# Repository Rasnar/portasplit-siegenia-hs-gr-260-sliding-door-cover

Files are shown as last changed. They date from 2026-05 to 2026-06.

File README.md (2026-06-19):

# Midea Portasplit Cover for Siegenia HS GR 260 Sliding Door

A parametric OpenSCAD adapter designed to fit the Midea Portasplit hose into a Siegenia HS GR 260 sliding door rail. This repository includes a repeatable middle piece, optional hose cutout, and top/bottom end caps for a clean, stackable installation.

## Supported hardware

- Siegenia HS GR 260 sliding door rail
- Midea Portasplit hose

> This model is tuned for these components. If you use a different rail profile or hose, verify the fit before printing.

## Contents

- `default-adapter.scad` — repeatable middle piece with optional hose slot
- `end-cap.scad` — top and bottom finishing caps for the assembly
- `default-adapter.3mf`, `portasplit-siegenia-adapter.3mf` — 3MF project files
- `default-adapter-10cm.stl`, `default-adapter-15cm.stl`, `default-adapter-20cm.stl` — preview STL exports
- `end-cap-top.stl`, `end-cap-bottom.stl` — cap preview models
- `LICENSE` — GNU GPLv3 license

## What this project does

This design creates a sliding-door-friendly cover for the Midea Portasplit hose inside the Siegenia HS GR 260 door rail. It uses:

- door-side tenons to engage the sliding door channel
- wall-side mortises and a center channel for fixed pin clearance
- dovetail-style tongues and grooves for vertical stacking
- an optional hose cutout that lets the hose pass through the part without detaching the assembly

## Recommended print setup

- Material: PETG is recommended for durability and fit
- Orientation: print vertically with the long face in Z
- Supports: minimal, only if your slicer requires them for small overhangs
- Layer height: 0.2mm or finer for best fit detail
- Tolerance: default `tolerance = 0.15`; adjust by ±0.05mm if the assembly feels too tight or loose

## Quick start

1. Open `default-adapter.scad` in OpenSCAD.
2. Set `hose_hole = true` to enable the hose slot, or `false` for a solid adapter piece.
3. Customize dimensions if needed, but keep the rail-specific interface values unless you are changing the rail geometry.
4. Render and export the model as STL or 3MF.
5. Use `end-cap.scad` with `part = "bottom"` for the bottom cap and `part = "top"` for the top cap.

## Usage examples

- Enable the hose slot:

```scad
hose_hole = true;
```

- Generate the bottom cap:

```scad
part = "bottom";
```

- Generate the top cap:

```scad
part = "top";
```

## Customization options

Key parameters in `default-adapter.scad`:

- `width`, `depth`, `height` — main body size
- `tenon_w`, `tenon_d`, `tenon_spacing` — door rail tenon fit
- `mortise_w`, `mortise_d`, `mortise_spacing` — wall-side mortises
- `channel_w` — center channel width for pins or obstacles
- `tongue_h`, `tongue_w_top`, `tongue_w_bot` — vertical dovetail stack geometry
- `hose_w`, `hose_h`, `hose_z`, `hose_tolerance` — hose aperture size and clearance
- `tolerance` — print fit offset for PETG

## Recommended workflow

- Print a short calibration slice first (30–40mm height)
- Check fit on the door rail and stack alignment before printing full-length pieces
- If the hose slot is enabled, verify the hose fits through the cutout cleanly
- Assemble one bottom cap, one or more middle pieces, and one top cap for a finished installation

## Notes for makers

- This design is optimized for the Siegenia HS GR 260 sliding door rail and Midea Portasplit hose geometry. Use caution if adapting to other rails.
- OpenSCAD parameter editing is the preferred way to create new lengths or custom fits.
- The current tolerance values are tuned for PETG; different friendly materials may require a new calibration print.

## What to improve next

If you want to make this repo stronger for public use, consider adding:

- preview photos or render images in the repo
- a `CHANGELOG.md` for versioned updates
- a small `assembly-guide.pdf` or `HOWTO` with installation photos
- additional height variants and a “no hose” version as separate exports
- a more explicit copyright header in the license

## License

This project is licensed under GNU GPLv3. See `LICENSE` for details.

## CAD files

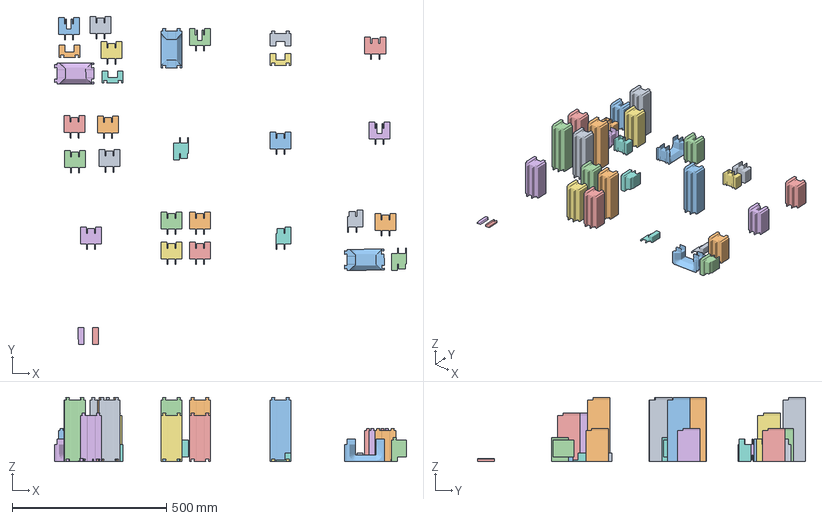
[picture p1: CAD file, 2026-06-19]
portasplit-siegenia-adapter.3mf
1139.5 x 1062.9 x 208.0 mm
end-cap-bottom.stl x 4
default-adapter-20cm.stl x 8
default-adapter-15cm.stl x 4
default-adapter-with-inner-hole-10cm.stl x 3
portasplit-hose-adapter.stl x 3
end-cap-top.stl x 6
default-adapter-10cm.stl x 2

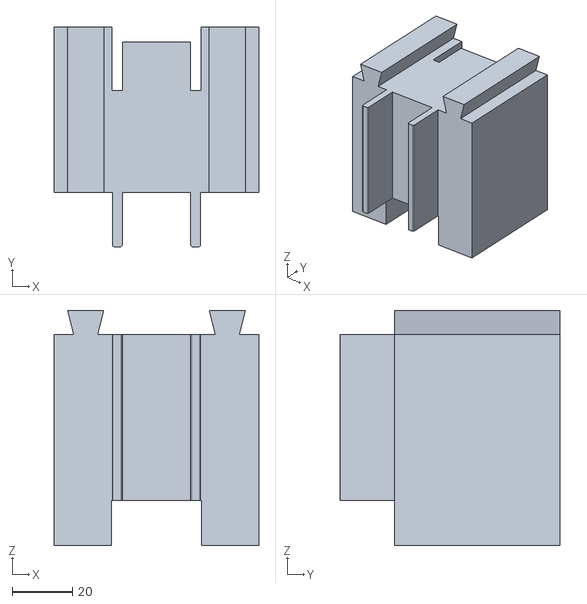
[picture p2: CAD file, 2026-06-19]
end-cap-bottom.stl
68.0 x 73.0 x 78.0

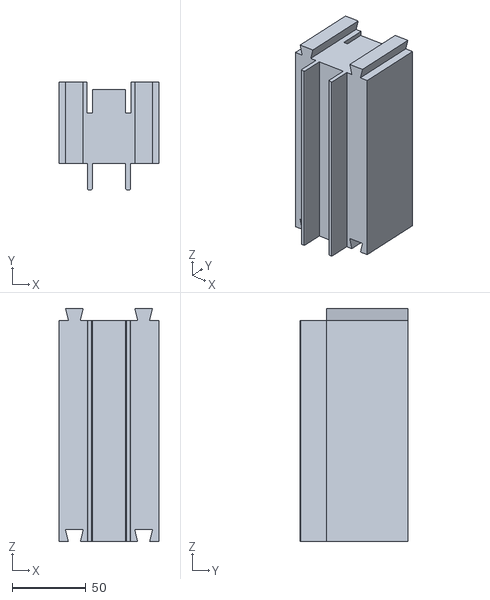
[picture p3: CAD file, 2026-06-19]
default-adapter-15cm.stl
68.0 x 73.0 x 158.0

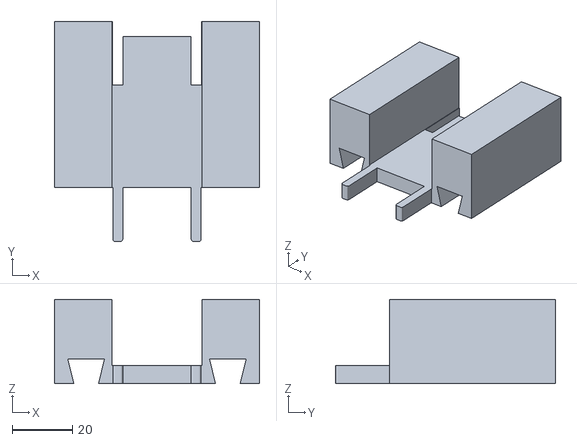
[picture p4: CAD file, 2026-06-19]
end-cap-top.stl
68.0 x 73.0 x 28.0

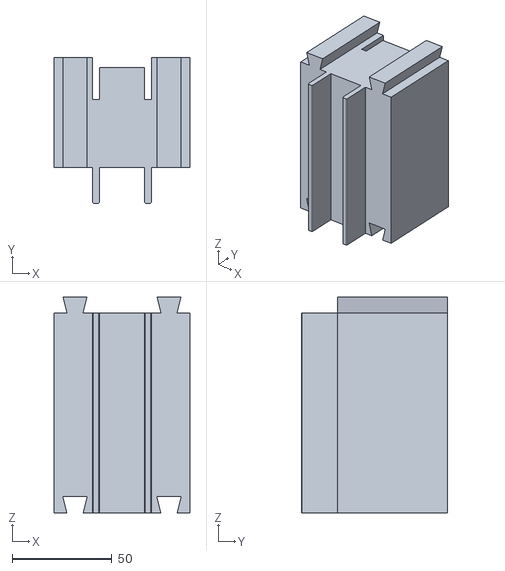
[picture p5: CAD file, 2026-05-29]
default-adapter-10cm.stl
68.0 x 73.0 x 108.0

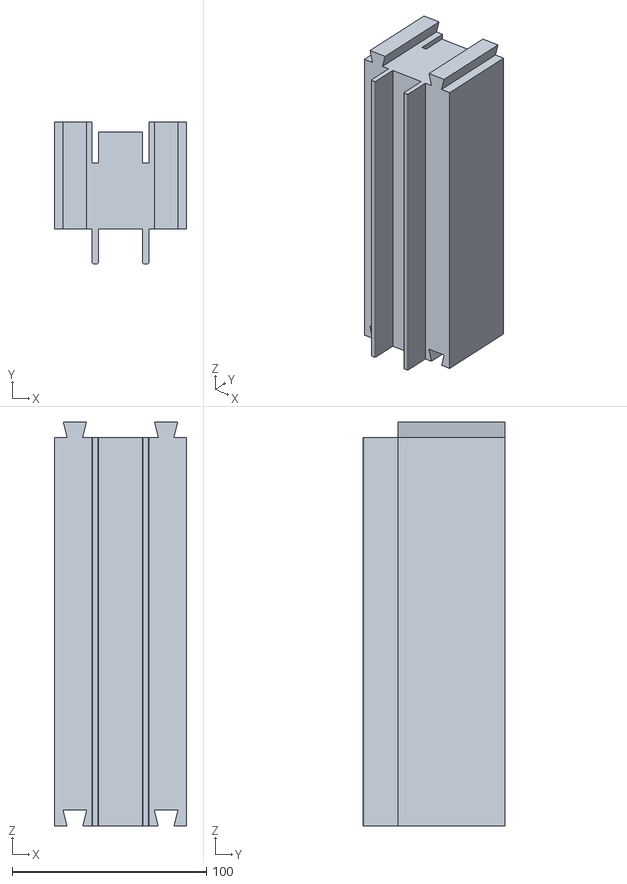
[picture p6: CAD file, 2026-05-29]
default-adapter-20cm.stl
68.0 x 73.0 x 208.0

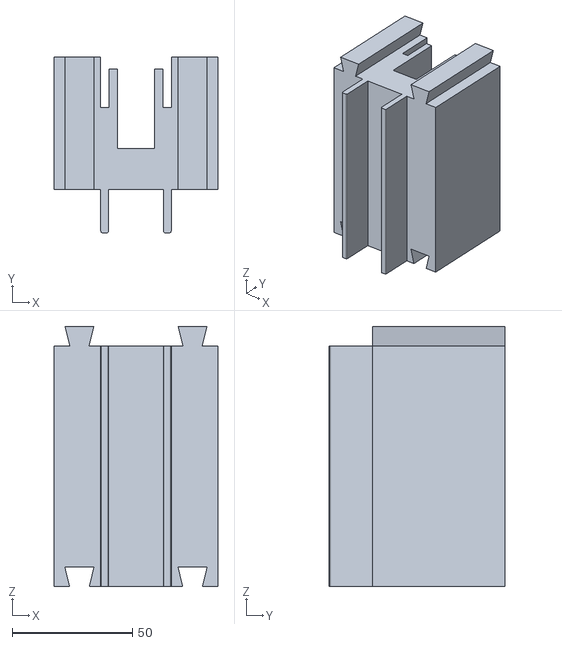
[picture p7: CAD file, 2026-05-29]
default-adapter-with-inner-hole-10cm.stl
68.0 x 73.0 x 108.0

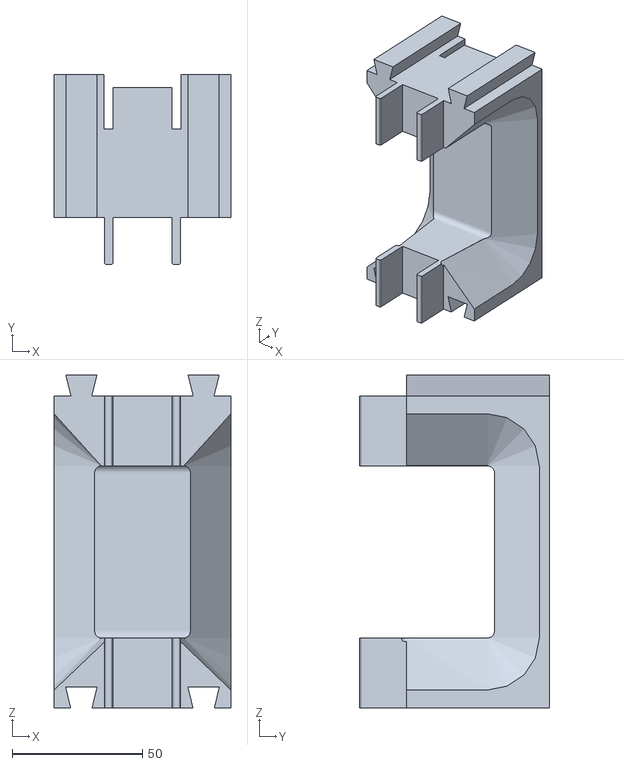
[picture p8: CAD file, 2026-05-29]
portasplit-hose-adapter.stl
68.0 x 73.0 x 128.0

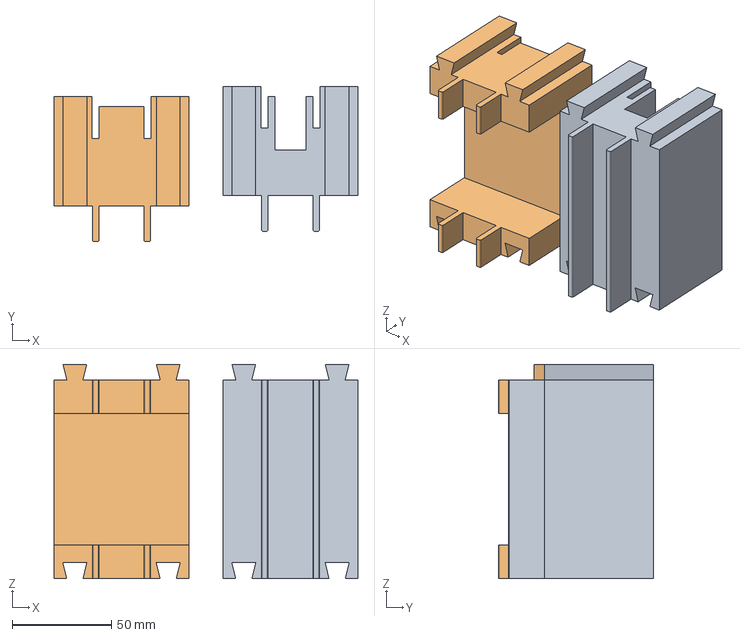
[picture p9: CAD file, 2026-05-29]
default-adapter.3mf
153.1 x 78.2 x 108.0 mm
default-adapter-with-innter-wall.stl
portasplit-hose-adapter.stl

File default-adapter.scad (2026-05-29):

// ============================================================
// Midea Portasplit Cover - Repeatable middle piece
// Siegenia HS GR 260 sliding door rail
// ============================================================

// Piece dimensions
width       = 68;
depth       = 55;
height      = 100;

// Door-side tenons (protrude toward door in -Y direction)
tenon_w         = 3.3;
tenon_d         = 18;
tenon_h         = height;   // Z-height of door tenons (defaults to full piece height)
tenon_corner_r  = 0.8;      // Corner radius of door tenons (0 = sharp)
tenon_spacing   = 26;

// Wall-side mortises (cut into back face, +Y side)
mortise_w       = 3.5;
mortise_d       = 30;        // Overall Y extent of wall-side engagement zone
ear_d           = 0;         // Y-depth of exterior ear blocks (shorter = less reach from back face)
inner_tenon_d   = 38;        // Put it to 38mm when need to clear tenon from window
                             // Use 5 when nothing in the channel
mortise_inner_d = 21;        // Mortise slot depth — matches tenon length by default
mortise_end_h   = 5;         // Height of exterior ears at top and bottom
mortise_spacing = 26;

// Wall-side structural details
mortise_wall_thickness = 3.5;  // Minimum wall each side of center channel
channel_w               = 15;  // Center channel width

// Dovetail tongue/groove (vertical assembly via top/bottom faces)
tongue_h      = 8;
tongue_w_top  = 12;
tongue_w_bot  = 8;

// Tolerance for all fits (PETG)
tolerance = 0.15;

// Derived positions
tenon_left_x  = width / 2 - tenon_spacing / 2;
tenon_right_x = width / 2 + tenon_spacing / 2;

// Tongue centers positioned symmetrically outside tenon zones
tongue_left_center_x  = tenon_left_x / 2;
tongue_right_center_x = tenon_right_x + (width - tenon_right_x) / 2;

// Channel bounds: mortises + wall thickness on each side
mortise_left_x  = width / 2 - mortise_spacing / 2;
mortise_right_x = width / 2 + mortise_spacing / 2;
channel_x_min   = mortise_left_x + mortise_w / 2 + mortise_wall_thickness;
channel_x_max   = mortise_right_x - mortise_w / 2 - mortise_wall_thickness;

inner_wall_d = depth - 5; // Depth of inner walls between mortise slots and channel

// Portasplit hose slot (27mm × 60mm flat hose, Midea Portasplit)
// Through-hole in X (side face to side face); open at window face (Y=0) for non-detachable hose.
hose_hole      = false;          // Set true to cut hose slot in this block
hose_w         = 31;            // Hose thickness → slot depth from window face (Y direction)
hose_h         = 66;            // Hose face → slot height (Z direction)
hose_z         = height / 2;    // Z center of hose slot (default: piece center)
hose_tolerance = 0.1;           // Clearance per side
hose_corner_r  = 2.8;             // Fillet on back-wall corners inside the slot (window face stays sharp)
outer_fillet_r = 20;             // Fillet around hole perimeter at each side face (cable exits here)

// ============================================================
// COMPONENT MODULES
// ============================================================

// Door-side tenon: rounded at door-tip only, square at body base
module door_tenon(x_pos) {
    r = tenon_corner_r;
    translate([x_pos - tenon_w / 2, -tenon_d, 0])
        hull() {
            // Door-tip: two cylinders give a rounded end
            translate([r,         r, 0]) cylinder(r=r, h=tenon_h, $fn=32);
            translate([tenon_w-r, r, 0]) cylinder(r=r, h=tenon_h, $fn=32);
            // Body base: full-width flat slice — keeps this end square
            translate([0, tenon_d - 0.01, 0]) cube([tenon_w, 0.01, tenon_h]);
        }
}

// Wall-side exterior ear: small block at top or bottom, flanks each mortise
// side: "left" or "right" relative to mortise center
// z_pos: "top" or "bottom"
module exterior_ear(mortise_x, side, z_pos) {
    ear_x = (side == "left") 
        ? mortise_x - mortise_w / 2 - 5 
        : mortise_x + mortise_w / 2;
    ear_z = (z_pos == "top") 
        ? height - mortise_end_h 
        : 0;
    
    translate([ear_x, depth, ear_z])
        cube([5, ear_d, mortise_end_h]);
}

// Dovetail tongue on top face: trapezoidal cross-section in X-Z plane
// Narrow at base (tongue_w_bot), wide at tip (tongue_w_top) — ~14° half-angle with defaults
// Inserted by sliding piece horizontally (X direction); wide tip locks against groove opening
module dovetail_tongue(tongue_center_x) {
    translate([tongue_center_x, 0, height])
        hull() {
            translate([-tongue_w_bot / 2, 0, 0])
                cube([tongue_w_bot, depth, 0.01]);
            translate([-tongue_w_top / 2, 0, tongue_h - 0.01])
                cube([tongue_w_top, depth, 0.01]);
        }
}

// Portasplit hose slot: open at window face (Y=0), through-hole in X
// Back-wall (Y=sd) corners are rounded internally; window face (Y=0) stays sharp
module hose_slot() {
    sd = hose_w + hose_tolerance;
    sh = hose_h + 2 * hose_tolerance;
    r  = hose_corner_r;
    // Front cylinders at Y=-1 (outside body) → window face remains a sharp rectangle
    // Back cylinders at Y=sd → back-wall corners are rounded with radius r
    hull() {
        for (zoff = [r, sh - r])
            for (yoff = [-1, sd])
                translate([-1, yoff, hose_z - sh/2 + zoff])
                    rotate([0, 90, 0])
                        cylinder(r=r, h=width+2, $fn=32);
    }
}

// Outer perimeter fillet: rounded lip on each X face.
// Uses the arc centered at (r, zt+r) / (r, zb-r): xi = r(1-cosθ), ri = r(1-sinθ).
// This arc has a HORIZONTAL tangent at the face (xi=0, ri=r) — the surface starts flush
// with the face and curves smoothly inward, creating a visible rounded lip on the outside
// of the slot edge rather than a funnel hole going into the piece.
module hose_outer_fillet() {
    sd  = hose_w + hose_tolerance;
    sh  = hose_h + 2 * hose_tolerance;
    r   = outer_fillet_r;
    zb  = hose_z - sh / 2;
    zt  = hose_z + sh / 2;
    N   = 16;
    eps = 0.01;

    // Left face (x=0)
    hull() {
        for (i = [0:N-1])
            for (yc = [0, sd])
                for (zc = [zb, zt])
                    translate([r * (1 - cos(90 * i / N)), yc, zc])
                        rotate([0, 90, 0])
                            cylinder(r = r * (1 - sin(90 * i / N)), h = eps, $fn = 16);
        translate([r, 0, zb]) cylinder([eps, sd, sh]);
    }

    // Right face (x=width)
    hull() {
        for (i = [0:N-1])
            for (yc = [0, sd])
                for (zc = [zb, zt])
                    translate([width - r * (1 - cos(90 * i / N)), yc, zc])
                        rotate([0, 90, 0])
                            cylinder(r = r * (1 - sin(90 * i / N)), h = eps, $fn = 16);
        translate([width - r, 0, zb]) cylinder([eps, sd, sh]);
    }
}

// Dovetail groove on bottom face: complement of tongue, with tolerance applied
// Opening (Z=0) is narrow, depth (Z=tongue_h) is wide — tongue tip can't exit through opening
module dovetail_groove(tongue_center_x) {
    translate([tongue_center_x, -1, 0])
        hull() {
            translate([-(tongue_w_bot + tolerance) / 2, 0, 0])
                cube([tongue_w_bot + tolerance, depth + 2, 0.01]);
            translate([-(tongue_w_top + tolerance) / 2, 0, tongue_h + tolerance - 0.01])
                cube([tongue_w_top + tolerance, depth + 2, 0.01]);
        }
}


// ============================================================
// MAIN GEOMETRY
// ============================================================

module portasplit_cover() {
    difference() {
        // Additive features
        union() {
            // Main body
            cube([width, depth, height]);

            // Door-side tenons
            door_tenon(tenon_left_x);
            door_tenon(tenon_right_x);

            // Wall-side exterior ears (structural support around mortises)
            for (mortise_x = [mortise_left_x, mortise_right_x]) {
                exterior_ear(mortise_x, "left", "top");
                exterior_ear(mortise_x, "left", "bottom");
                exterior_ear(mortise_x, "right", "top");
                exterior_ear(mortise_x, "right", "bottom");
            }

            // Dovetail tongues on top face (for vertical stacking)
            dovetail_tongue(tongue_left_center_x);
            dovetail_tongue(tongue_right_center_x);
        }

        // Subtractive features (cuts)

        // Inner walls: cut from wall side inward, leaving inner_wall_d depth from door side
        translate([mortise_left_x + mortise_w / 2, inner_wall_d, -1])
            cube([mortise_wall_thickness, depth - inner_wall_d + 1, height + 2]);
        translate([channel_x_max, inner_wall_d, -1])
            cube([mortise_wall_thickness, depth - inner_wall_d + 1, height + 2]);
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

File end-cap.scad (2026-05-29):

// ============================================================
// Portasplit End Cap — Top and Bottom finishing pieces
// Siegenia HS GR 260 sliding door rail
// ============================================================
//
// Set `part` to generate either cap:
//   "top"    — dovetail groove on bottom face (female), flat top face
//   "bottom" — dovetail tongue on top face (male), flat bottom face
//
// The terminal face (top for "bottom" cap, bottom for "top" cap)
// can have one or two through-holes running the full Y depth
// (door-tenon side through to wall side).  These replace the
// dovetail that would exist on a middle piece at that position.
//
// No hose slot — end caps do not pass the Portasplit hose.
// All other dimensions identical to default-adapter.scad.

// ── Which piece to generate ──────────────────────────────
part = "top";   // "top" | "bottom"

// ── Piece dimensions ──────────────────────────────────────
width  = 68;
depth  = 55;
height = 40;

// ── Door-side tenons ──────────────────────────────────────
tenon_w        = 3.3;
tenon_d        = 18;
tenon_h        = height;
tenon_corner_r = 0.8;
tenon_spacing  = 26;

// ── Wall-side mortises ────────────────────────────────────
mortise_w              = 3.5;
mortise_d              = 30;
ear_d                  = 0;
inner_tenon_d          = 5;
mortise_inner_d        = 21;
mortise_end_h          = 5;
mortise_spacing        = 26;

// ── Wall-side structural details ──────────────────────────
mortise_wall_thickness = 3.5;
channel_w              = 15;

// ── Dovetail tongue / groove ──────────────────────────────
tongue_h     = 8;
tongue_w_top = 12;
tongue_w_bot = 8;

// ── Tolerance (PETG) ─────────────────────────────────────
tolerance = 0.15;

// ── Through-hole on terminal face ────────────────────────
// Single centered hole running the full Y axis: from tenon tips
// (-tenon_d) through to the wall face (+depth).
// Placed on the face OPPOSITE the dovetail:
//   "bottom" cap → bottom face (Z = 0)
//   "top"    cap → top face    (Z = height)
through_hole  = true;   // enable / disable
hole_w        = 30;     // hole width in X [mm]
hole_h_top    = 22;     // hole height in Z for top cap    [mm]
hole_h_bottom = 15;     // hole height in Z for bottom cap [mm]

hole_h = (part == "top") ? hole_h_top : hole_h_bottom;

// ── Derived positions ─────────────────────────────────────
tenon_left_x  = width / 2 - tenon_spacing / 2;
tenon_right_x = width / 2 + tenon_spacing / 2;

tongue_left_center_x  = tenon_left_x / 2;
tongue_right_center_x = tenon_right_x + (width - tenon_right_x) / 2;

mortise_left_x  = width / 2 - mortise_spacing / 2;
mortise_right_x = width / 2 + mortise_spacing / 2;
channel_x_min   = mortise_left_x + mortise_w / 2 + mortise_wall_thickness;
channel_x_max   = mortise_right_x - mortise_w / 2 - mortise_wall_thickness;

inner_wall_d = depth - 5;

// Z start of through-hole — opposite face from the dovetail
// "bottom" cap: dovetail on top  → hole on bottom face (Z = 0)
// "top"    cap: dovetail on bottom → hole on top face (Z = height - hole_h)
hole_z0 = (part == "bottom") ? 0 : height - hole_h;

// ============================================================
// COMPONENT MODULES  (identical to default-adapter.scad)
// ============================================================

module door_tenon(x_pos) {
    r = tenon_corner_r;
    translate([x_pos - tenon_w / 2, -tenon_d, 0])
        hull() {
            translate([r,         r, 0]) cylinder(r=r, h=tenon_h, $fn=32);
            translate([tenon_w-r, r, 0]) cylinder(r=r, h=tenon_h, $fn=32);
            translate([0, tenon_d - 0.01, 0]) cube([tenon_w, 0.01, tenon_h]);
        }
}

module exterior_ear(mortise_x, side, z_pos) {
    ear_x = (side == "left")
        ? mortise_x - mortise_w / 2 - 5
        : mortise_x + mortise_w / 2;
    ear_z = (z_pos == "top")
        ? height - mortise_end_h
        : 0;
    translate([ear_x, depth, ear_z])
        cube([5, ear_d, mortise_end_h]);
}

module dovetail_tongue(tongue_center_x) {
    translate([tongue_center_x, 0, height])
        hull() {
            translate([-tongue_w_bot / 2, 0, 0])
                cube([tongue_w_bot, depth, 0.01]);
            translate([-tongue_w_top / 2, 0, tongue_h - 0.01])
                cube([tongue_w_top, depth, 0.01]);
        }
}

module dovetail_groove(tongue_center_x) {
    translate([tongue_center_x, -1, 0])
        hull() {
            translate([-(tongue_w_bot + tolerance) / 2, 0, 0])
                cube([tongue_w_bot + tolerance, depth + 2, 0.01]);
            translate([-(tongue_w_top + tolerance) / 2, 0, tongue_h + tolerance - 0.01])
                cube([tongue_w_top + tolerance, depth + 2, 0.01]);
        }
}

// Single centered through-hole running full Y depth.
// Rectangular cross-section: hole_w (X) × hole_h (Z).
module through_hole_cut() {
    y0 = -tenon_d - 1;         // start beyond tenon tips
    yl = depth + tenon_d + 2;  // full Y span including tenon protrusion
    translate([width / 2 - hole_w / 2, y0, hole_z0])
        cube([hole_w, yl, hole_h]);
}

// ============================================================
// MAIN
// ============================================================

module end_cap() {
    difference() {
        union() {
            cube([width, depth, height]);

            door_tenon(tenon_left_x);
            door_tenon(tenon_right_x);

            for (mortise_x = [mortise_left_x, mortise_right_x]) {
                exterior_ear(mortise_x, "left",  "top");
                exterior_ear(mortise_x, "left",  "bottom");
                exterior_ear(mortise_x, "right", "top");
                exterior_ear(mortise_x, "right", "bottom");
            }

            // "bottom" cap: tongue on top face connects to the piece above
            if (part == "bottom") {
                dovetail_tongue(tongue_left_center_x);
                dovetail_tongue(tongue_right_center_x);
            }
        }

        // Inner wall slots
        translate([mortise_left_x + mortise_w / 2, inner_wall_d, -1])
            cube([mortise_wall_thickness, depth - inner_wall_d + 1, height + 2]);
        translate([channel_x_max, inner_wall_d, -1])
            cube([mortise_wall_thickness, depth - inner_wall_d + 1, height + 2]);

        // Wall-side mortises
        for (mortise_x = [mortise_left_x, mortise_right_x]) {
            translate([mortise_x - mortise_w / 2, depth - mortise_inner_d, -1])
                cube([mortise_w, mortise_inner_d + 1, height + 2]);
        }

        // Wall-side center channel
        translate([channel_x_min, depth - inner_tenon_d, -1])
            cube([channel_x_max - channel_x_min, inner_tenon_d + 1, height + 2]);

        // "top" cap: groove on bottom face receives the tongue from the piece below
        if (part == "top") {
            dovetail_groove(tongue_left_center_x);
            dovetail_groove(tongue_right_center_x);
        }

        // Through-hole on terminal face (opposite side from dovetail)
        if (through_hole)
            through_hole_cut();
    }
}

end_cap();

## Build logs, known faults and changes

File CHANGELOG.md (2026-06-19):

# Changelog

All notable changes to this project will be documented in this file.

## [1.0.0] - 2026-06-19
- Initial public release
- Added `default-adapter.scad` for the repeatable middle piece
- Added `end-cap.scad` for top and bottom finishing caps
- Included preview STL and 3MF exports
- Added README with usage and print guidance
- Licensed under GNU GPLv3

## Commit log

2026-05-28 feat: base design for siegenia sliding door cache for midea portasplit
    [default-adapter-with-innter-wall.stl, default-adapter.3mf, default-adapter.scad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]
2026-05-29 feat: round corners on portasplit adapter
    [default-adapter-with-innter-wall.stl, default-adapter.3mf, default-adapter.scad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]
2026-05-29 feat: add top and bottom cap
    [default-adapter-10cm.stl, default-adapter-20cm.stl, default-adapter-with-inner-hole-10cm.stl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]
2026-06-19 feat: add 3mf file and new stl exports
    [default-adapter-15cm.stl, end-cap-bottom.stl, end-cap-top.stl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]
2026-06-19 export setup for release
    [portasplit-siegenia-adapter.3mf]
